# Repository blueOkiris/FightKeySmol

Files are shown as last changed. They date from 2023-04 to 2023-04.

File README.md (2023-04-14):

# Fight Key Smol

## Description

I made a [hitbox for myself](https://hackaday.io/project/185796-fight-key-wide) a while back that's big and has an enclosure and all that good stuff and cost me maybe $80 to make.

However, lately I've been seeing people pay well over $100 for something that should be maybe $50 max, so I'm redesigning that to fit the style people want, so there's a cheap alternative.

Now yes, you're paying for quality with the others. This doesn't come with an enclosure, and it's DIY; it's minimal, but for some people, that's worth not dropping >= $100. It's an option. That's all

So, this project aims to be a tiny, inexpensive, DIY, keyboard-based fighting-game controller.

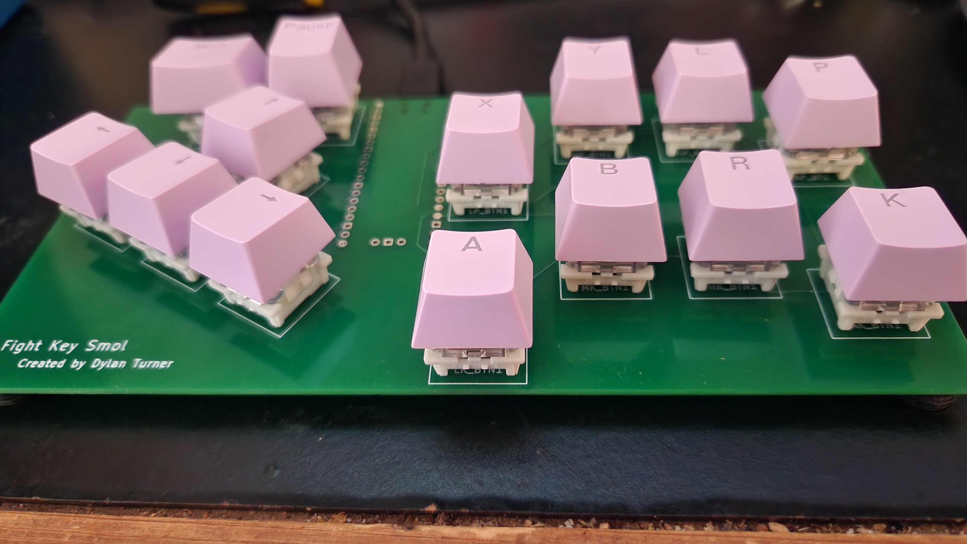
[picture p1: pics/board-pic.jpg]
Image of Physical Fight Key


## Software

The software included in the repo and releases is a pre-built version of the [GP2040-CE](https://github.com/OpenStickCommunity/GP2040-CE) firmware.

For version 1, there is a custom version due to Start and Select being switched. For version 2, this is not the case, and the stock software can be used.

## Parts

It currently costs \~$32 for materials, but shipping is another $10, so I will likely continue to look for more options to cut costs as even $40 is absurd.

| Part | Link | Cost |
|:---:|:---:|:----:|
| PCB | [Jlcpcb](https://jlcpcb.com/) | $10  |
| PCB Shipping | Choose Global Standard for cheaper | $10  |
| Switches | [Amazon][SwitchLink] | $7 |
| Key Caps | [Aliexpress][CapLink] | $2 |
| Pico | [Amazon][PicoLink] | $8 |
| Rubber Feet  | [Aliexpress][FeetLink] (Hot Glue is alternative) | $3 |
| Total | - | $40  |

There are probably cheaper ways to get parts like switches, but here's some starting points.

[SwitchLink]: https://www.amazon.com/Keyswitch-Replaceable-Switches-Mechanical-Keyboard/dp/B07V4S3QDK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 "Amazon"

[CapLink]: https://www.aliexpress.us/item/3256803462871478.html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 "Aliexpress"

[PicoLink]: https://www.amazon.com/seeed-studio-Raspberry-Microcontroller-Dual-core/dp/B08TQSDP28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 "Amazon"

[FeetLink]: https://www.aliexpress.us/item/3256802824831274.html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 "Aliexpress"

## Subdirectories

- pcb - Fight Key Smol KiCAD PCB project
- GP2040-CE - submodule containing code.
- pics - Pics used for the README

## Build Instructions

1. Order the board from Jlcpcb. Can just use default options
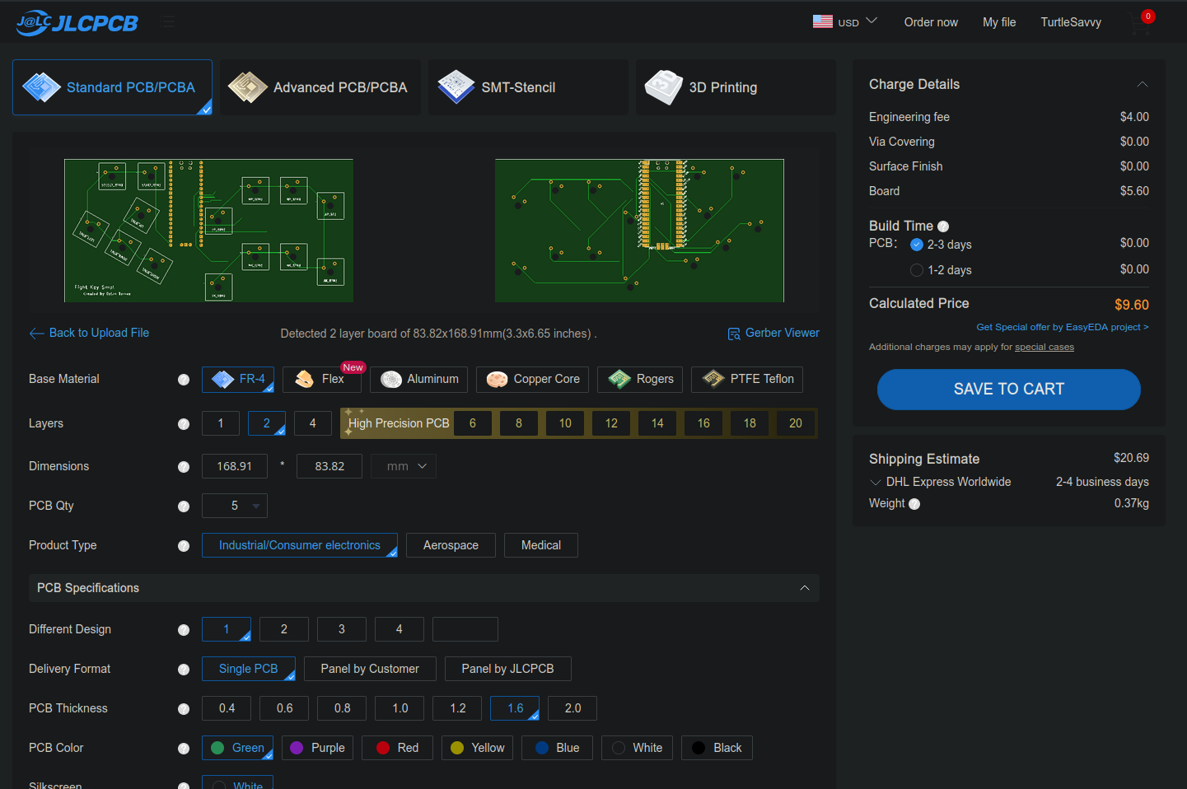
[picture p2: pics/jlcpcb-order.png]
jlcpcb order
   
2. Add feet.
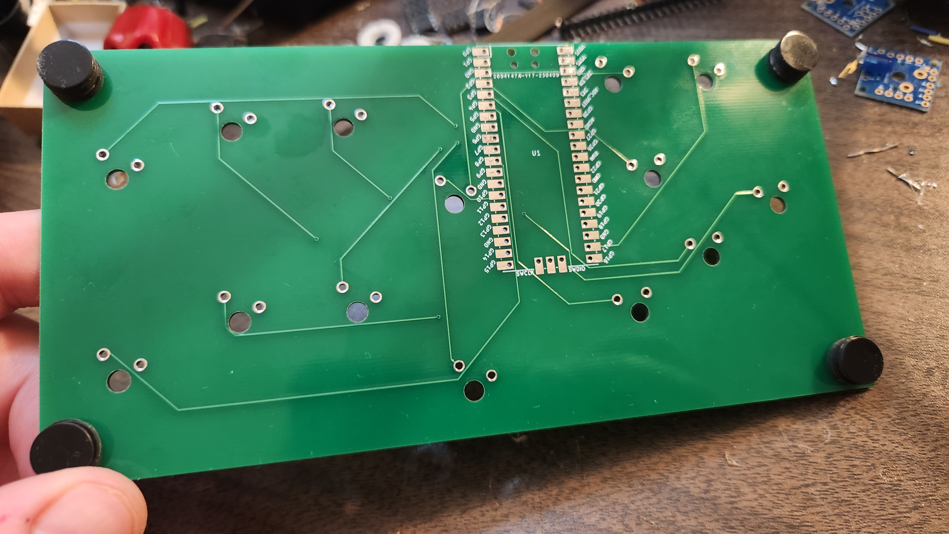
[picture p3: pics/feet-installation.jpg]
feet installation
   
3. Solder the pico to the board.
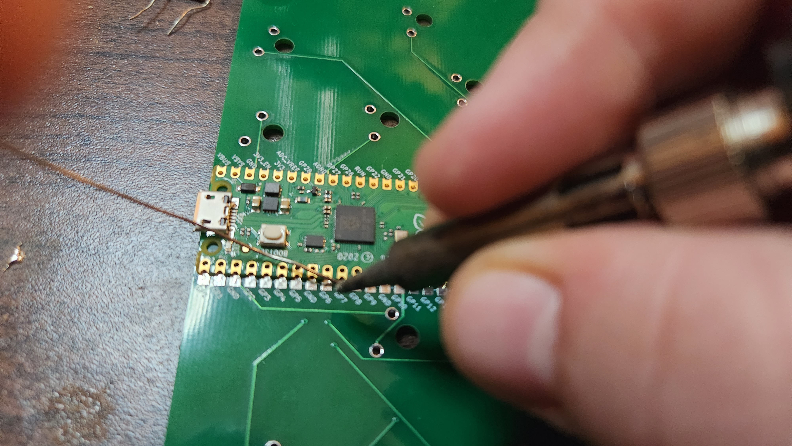
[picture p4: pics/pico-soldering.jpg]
pico soldering
   
4. Add caps.
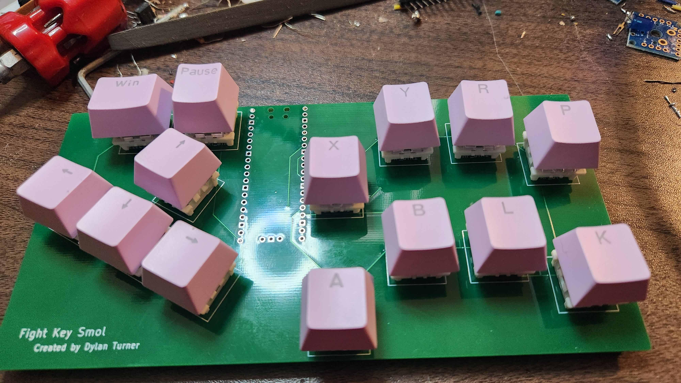
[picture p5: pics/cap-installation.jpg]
cap installation
   
5. Solder the switches to the board.
   - Press down to make sure they all get put evenly. You may need to 
   - If not even, you can reheat a joint and push on the switch to adjust the angle.
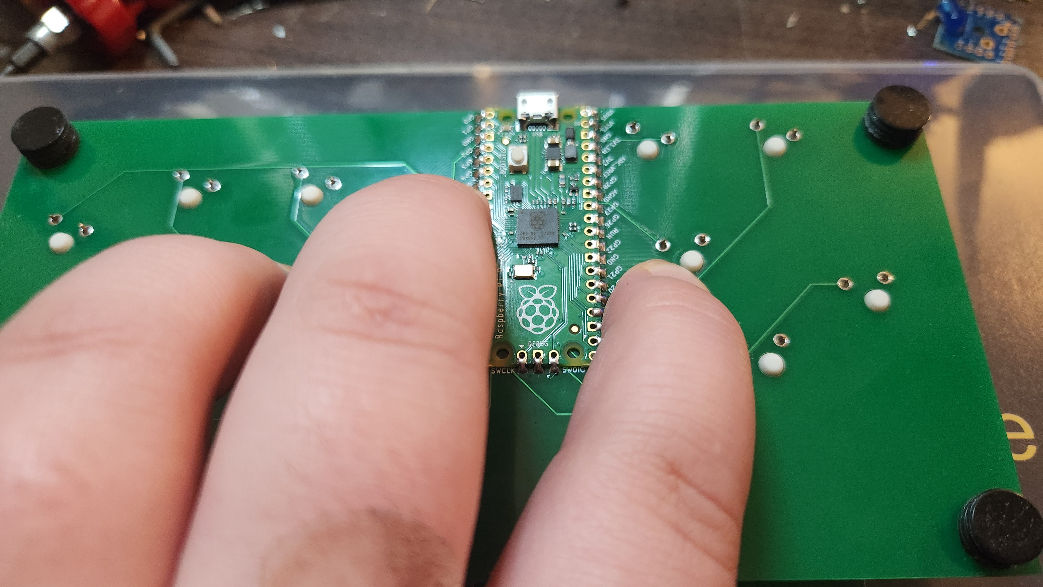
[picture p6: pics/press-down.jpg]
press down
   
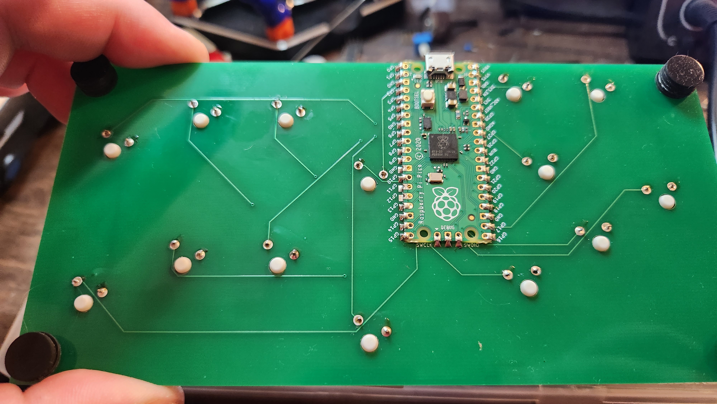
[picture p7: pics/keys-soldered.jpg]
switch soldering
   
6. Program the pico. You don't need to rebuild it.
   1. Press the pico's button down and plug it in to make it show up as a drive
   2. Copy the .uf2 file in the repo to the drive. It will unmount and program and auto-remount as a controller
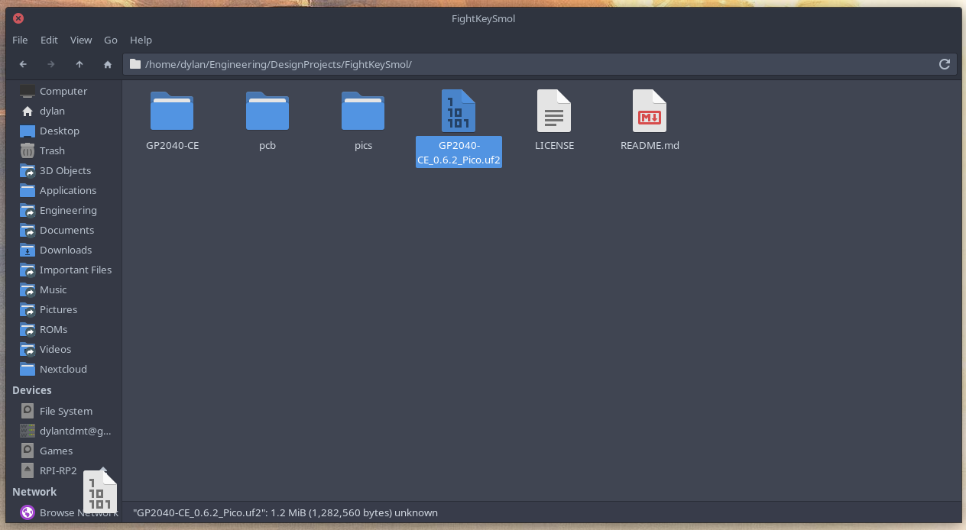
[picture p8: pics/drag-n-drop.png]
pico programming
   
7. Enjoy!

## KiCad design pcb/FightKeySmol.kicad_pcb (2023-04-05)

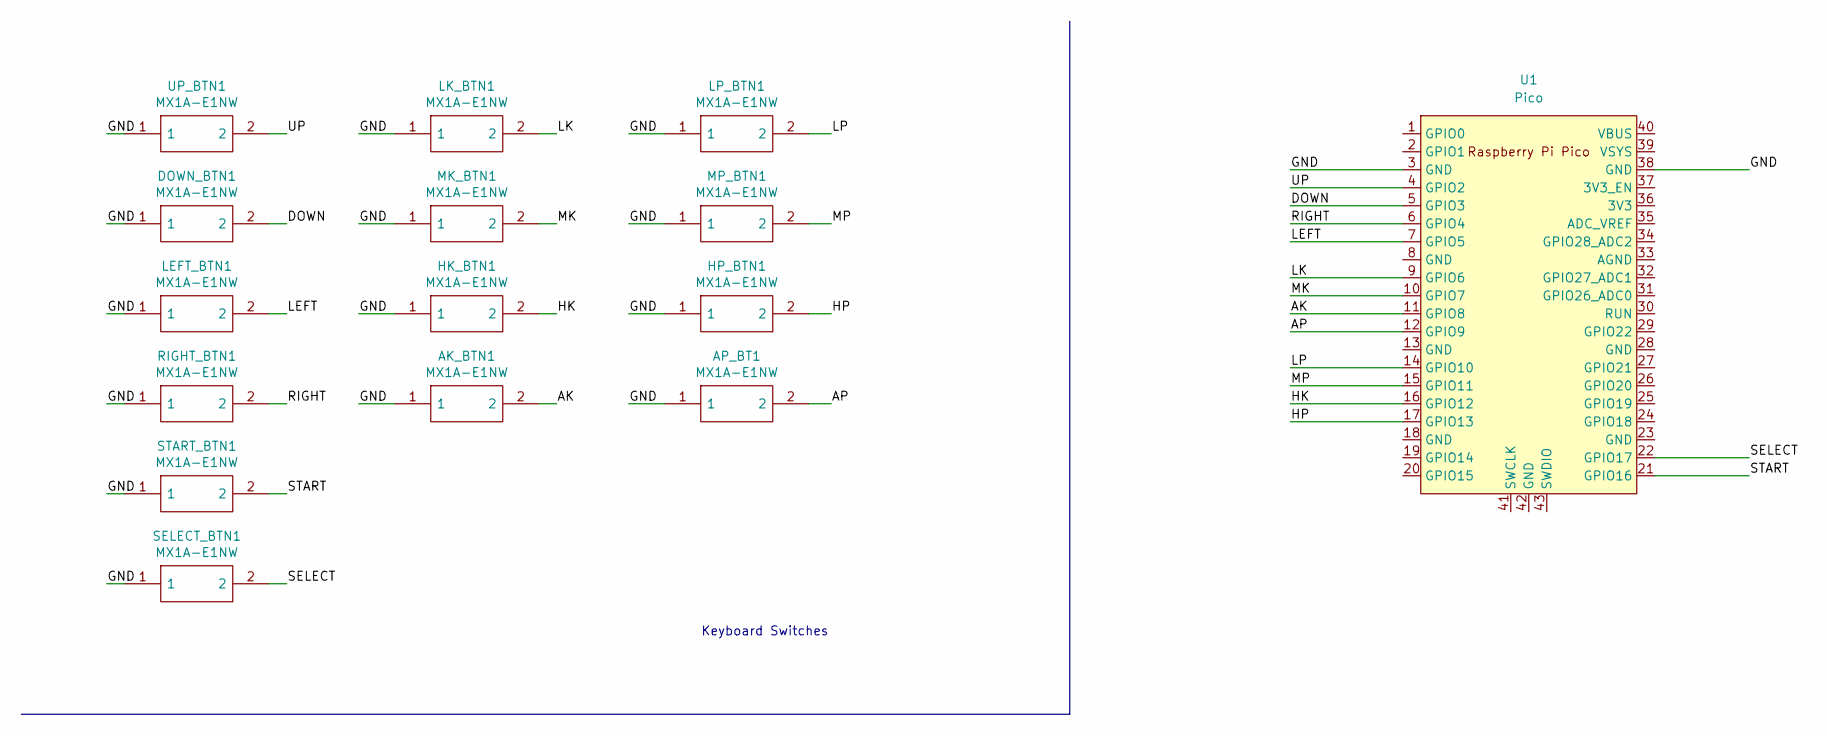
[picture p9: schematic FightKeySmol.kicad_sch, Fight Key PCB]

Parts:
AK_BTN1: MX1A-E1NW; MX1AE1NW; Mouser Part Number 540-MX1A-E1NW
AP_BT1: MX1A-E1NW; MX1AE1NW; Mouser Part Number 540-MX1A-E1NW
DOWN_BTN1: MX1A-E1NW; MX1AE1NW; Mouser Part Number 540-MX1A-E1NW
HK_BTN1: MX1A-E1NW; MX1AE1NW; Mouser Part Number 540-MX1A-E1NW
HP_BTN1: MX1A-E1NW; MX1AE1NW; Mouser Part Number 540-MX1A-E1NW
LEFT_BTN1: MX1A-E1NW; MX1AE1NW; Mouser Part Number 540-MX1A-E1NW
LK_BTN1: MX1A-E1NW; MX1AE1NW; Mouser Part Number 540-MX1A-E1NW
LP_BTN1: MX1A-E1NW; MX1AE1NW; Mouser Part Number 540-MX1A-E1NW
MK_BTN1: MX1A-E1NW; MX1AE1NW; Mouser Part Number 540-MX1A-E1NW
MP_BTN1: MX1A-E1NW; MX1AE1NW; Mouser Part Number 540-MX1A-E1NW
RIGHT_BTN1: MX1A-E1NW; MX1AE1NW; Mouser Part Number 540-MX1A-E1NW
SELECT_BTN1: MX1A-E1NW; MX1AE1NW; Mouser Part Number 540-MX1A-E1NW
START_BTN1: MX1A-E1NW; MX1AE1NW; Mouser Part Number 540-MX1A-E1NW
U1: Pico; RPi_Pico_SMD_TH
UP_BTN1: MX1A-E1NW; MX1AE1NW; Mouser Part Number 540-MX1A-E1NW

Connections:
/AK: AK_BTN1.2, U1.11 (GPIO8)
/AP: AP_BT1.2, U1.12 (GPIO9)
/DOWN: DOWN_BTN1.2, U1.5 (GPIO3)
/GND: AK_BTN1.1, AP_BT1.1, DOWN_BTN1.1, HK_BTN1.1, HP_BTN1.1, LEFT_BTN1.1, LK_BTN1.1, LP_BTN1.1, MK_BTN1.1, MP_BTN1.1, RIGHT_BTN1.1, SELECT_BTN1.1, START_BTN1.1, U1.3 (GND), U1.38 (GND), UP_BTN1.1
/HK: HK_BTN1.2, U1.16 (GPIO12)
/HP: HP_BTN1.2, U1.17 (GPIO13)
/LEFT: LEFT_BTN1.2, U1.7 (GPIO5)
/LK: LK_BTN1.2, U1.9 (GPIO6)
/LP: LP_BTN1.2, U1.14 (GPIO10)
/MK: MK_BTN1.2, U1.10 (GPIO7)
/MP: MP_BTN1.2, U1.15 (GPIO11)
/RIGHT: RIGHT_BTN1.2, U1.6 (GPIO4)
/SELECT: SELECT_BTN1.2, U1.22 (GPIO17)
/START: START_BTN1.2, U1.21 (GPIO16)
/UP: U1.4 (GPIO2), UP_BTN1.2

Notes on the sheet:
Keyboard Switches

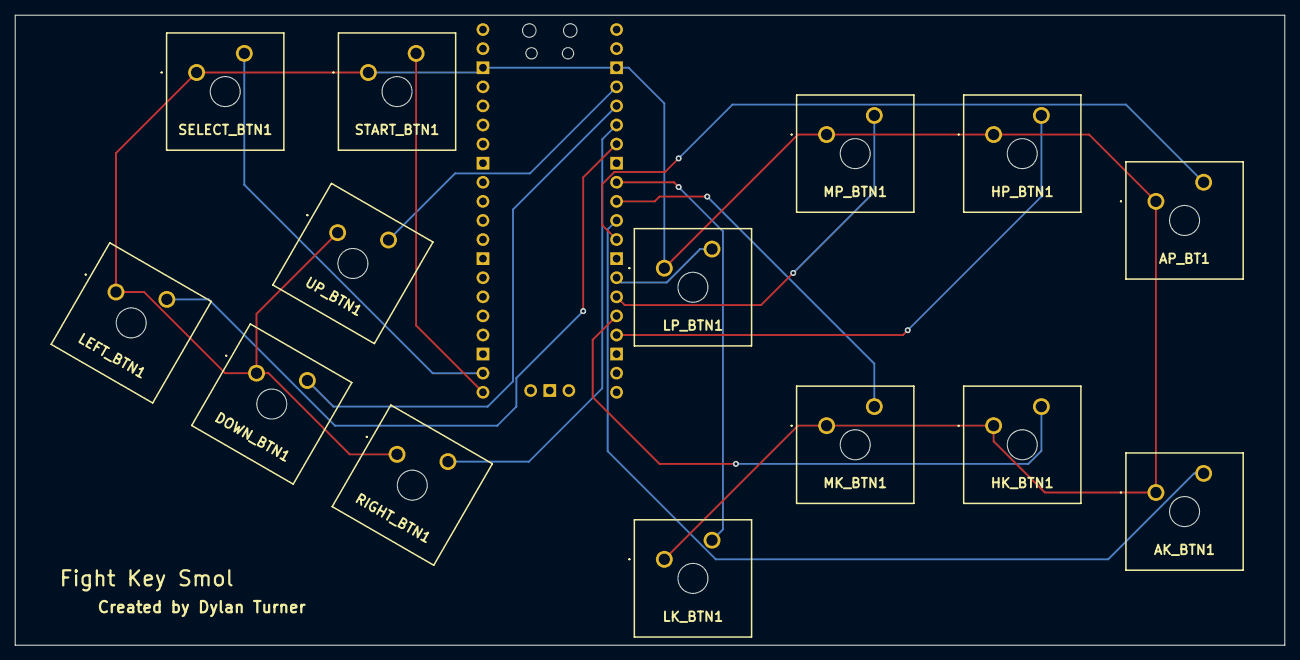
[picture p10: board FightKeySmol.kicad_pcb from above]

Board: 2 copper layers, 168.9 x 83.8 mm, 15 parts (1 on the bottom side), 15 nets.

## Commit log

2023-04-05 pcb: added from fightkey-wide proj
    [FightKeySmol.kicad_pcb, FightKeySmol.kicad_sch, FightKeySmol.sch]
2023-04-05 gitignore: ignore KiCAD output/backup files
2023-04-05 README: switches link points to cheap knockoffs
    No need for fancy ones since this is a low-end device
2023-04-05 kicad_sch: redesigned to use input_pullup
    This is the standard for GP2040 style sticks.
    Use PICO_BOARD_CONFIG_H_
    [FightKeySmol.kicad_sch]
2023-04-05 kicad_sch: added second ground on other side
    [FightKeySmol.kicad_sch]
2023-04-05 kicad_pcb: updated for schem and new tiny design
    [FightKeySmol.kicad_pcb]
2023-04-05 kicad_pcb: updated for new design
    [FightKeySmol.kicad_pcb]
2023-04-14 GP2040-CE_0.6.2_Pico: switched start/select
    I mixed up S1 and S2 when designing the PCB
2023-04-14 GP2040-CE: switched to custom version
2023-04-14 README: noted use of hot glue as feet alternative
